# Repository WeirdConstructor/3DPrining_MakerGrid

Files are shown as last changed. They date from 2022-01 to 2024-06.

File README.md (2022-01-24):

# MakerGrid - A 3D Printed grid system for makers

This system allows you to temporarily setup electronics or other
devices on an extensible modular base platform:

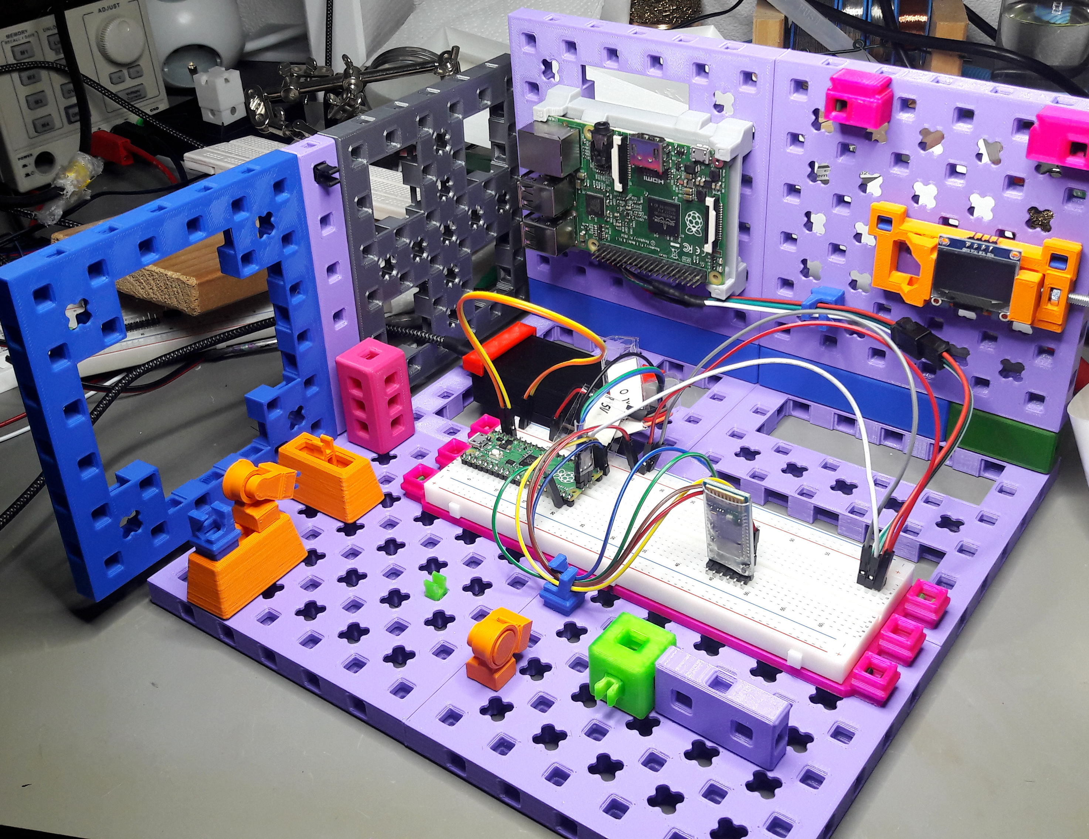
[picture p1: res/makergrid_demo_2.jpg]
MakerGrid Demonstration Prototype


The base is this 12x12cm big and 1cm high base platform:

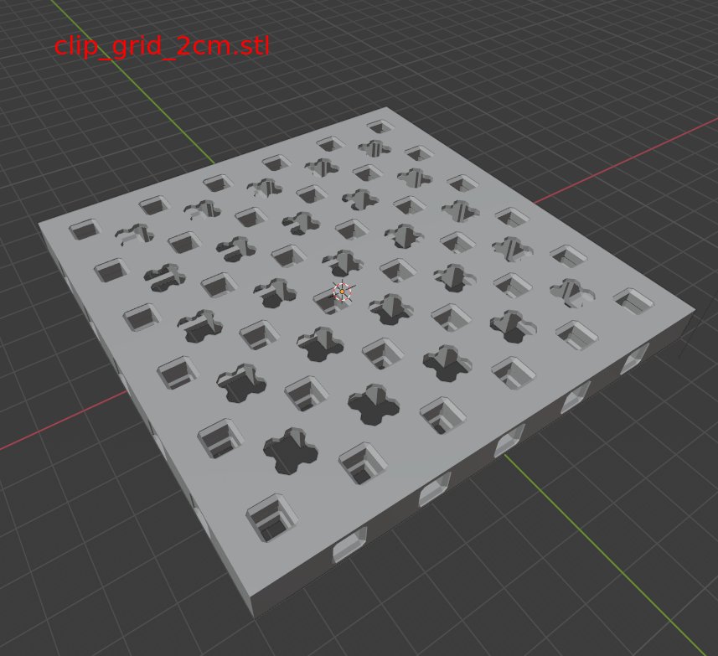
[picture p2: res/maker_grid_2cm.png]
MakerGrid 12x12cm base platform with 2x2cm clip grid


The primary base platform is 12x12cm big, 1cm high and has a 2x2cm grid for
clipping in all sorts of stuff, such as:

- Bread boards
- Electronics modules such as:
  - Arduino Uno / Nano
  - Raspberry Pi 4
  - Raspberry Pi Pico

The system is extensible as with the generic clip design you can make
your own models to clip into the board. A clip looks like this:

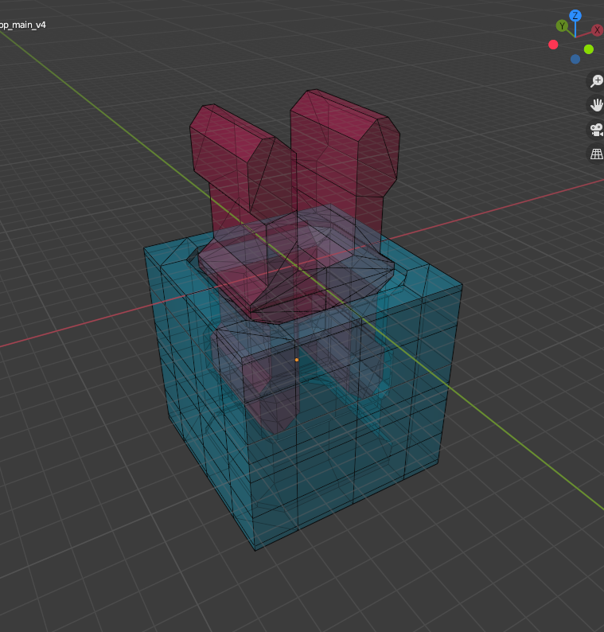
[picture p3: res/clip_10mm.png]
MakerGrid Clip


The clips hold well in the holes, you will need either strong fingers or
pliers to pull them out again. The clip arms will be printed with 3 0.4mm thick
walls, which provide enough flexibility while also holding tight.
The clips also provide a rotational stability.

The advantage of this system that connects holes is also,
that if you damage a clip, you can reprint them quickly.

There is a whole palette for holdes/clip holders to choose from in the `clip.blend`
file:

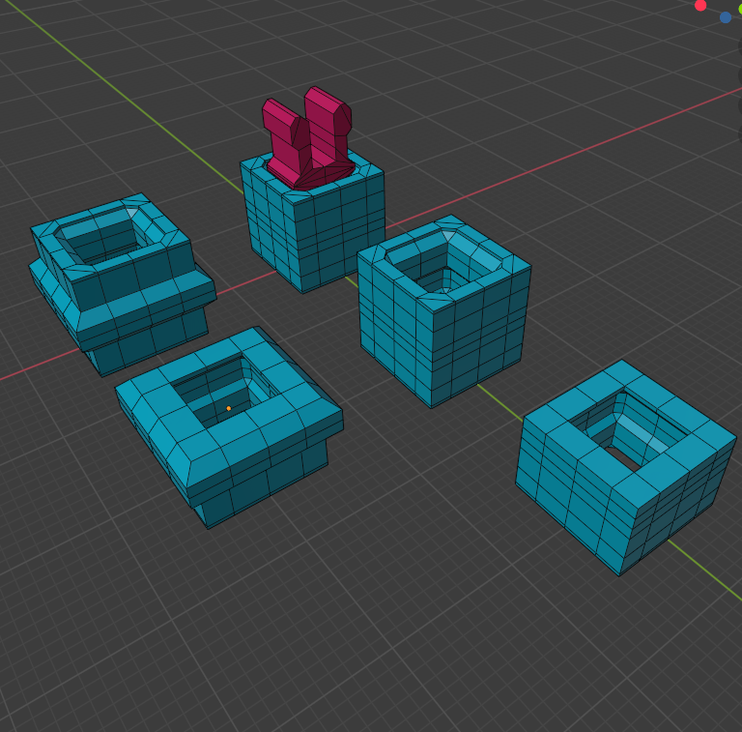
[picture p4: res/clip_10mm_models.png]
MakerGrid Clip Palette


## Prior Art

I was inspired by:

- 3D Printing Professor's PrintABlok
  - While I like this approach and it's design is superior to mine, I wanted
    something a bit more compact and less bulky.
  - https://www.youtube.com/watch?v=BU7ZYPHWDo4
  - https://www.3dpprofessor.com/product/printablok-base-set-free/
  - https://www.thingiverse.com/thing:4965875
- Pin Connectors V2
  - I like the simplicity of this design, but these round connectors
    would make the MakerGrid too wobbly if not connected by at least two
    pins. My grid clips are rectangular and already provide some stability
    if you just plug in a single one.
  - https://www.thingiverse.com/thing:10541

## Maker Grid Types:

- Regular Full:
MakerGrid 12x12cm base platform with 2x2cm clip grid
- Type B:
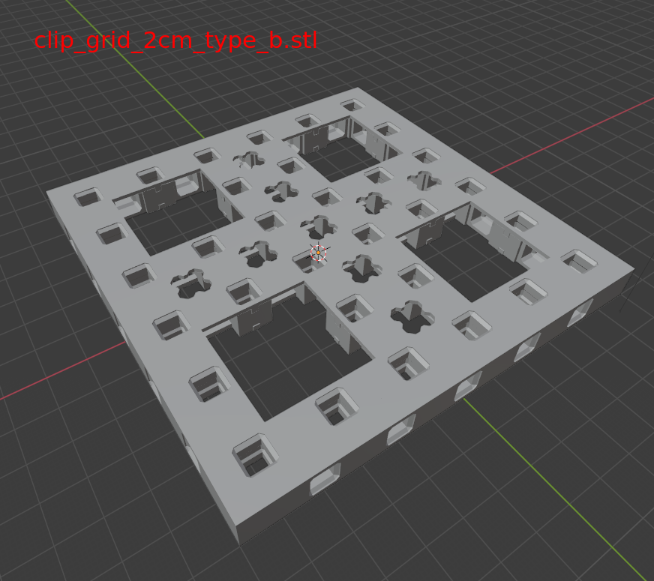
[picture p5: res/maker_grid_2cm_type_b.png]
MakerGrid 12x12cm base platform type B

- Type C:
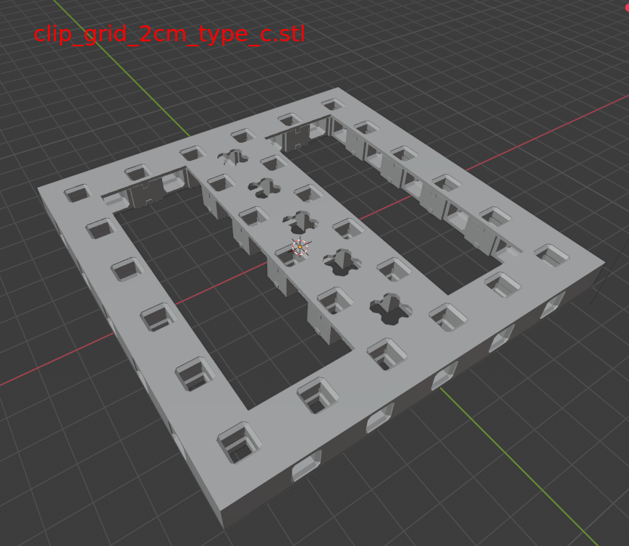
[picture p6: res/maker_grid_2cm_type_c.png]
MakerGrid 12x12cm base platform type C

- Type D:
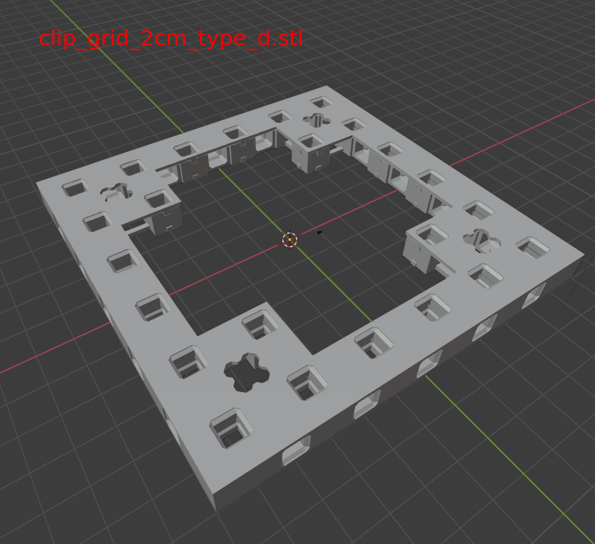
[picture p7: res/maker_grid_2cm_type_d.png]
MakerGrid 12x12cm base platform type D


## Utilities

- Build Cubes in sizes 1x1, 3x1, 7x1, 11x1, 15x1 offer a way to extend
  the maker grid into 3 dimensions.
    - Also with a slim variant that has the "\_s" as postfix.
    - And a base extension variant, that can be plugged to the side
      of the MakerGrid bases with an "\_x" postfix.

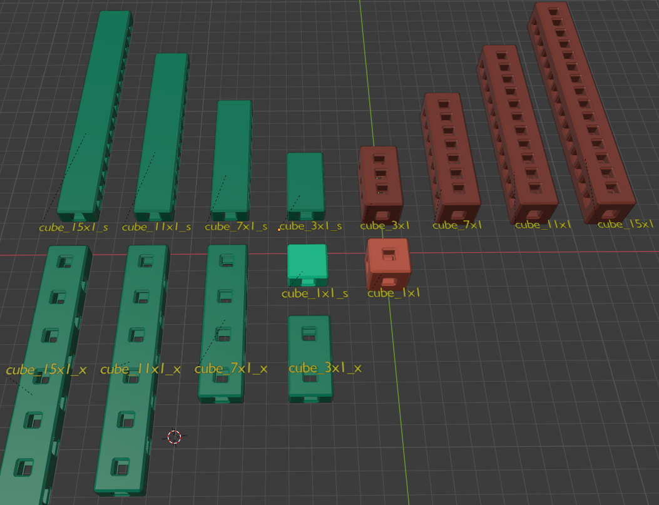
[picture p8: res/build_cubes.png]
MakerGrid Build Cubes


- Raspberry Pi 2/3/4 B Holder

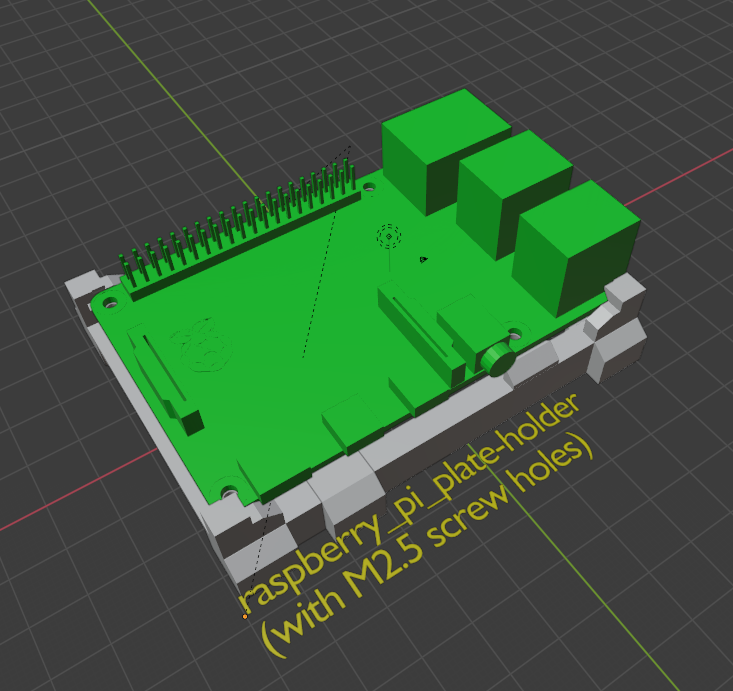
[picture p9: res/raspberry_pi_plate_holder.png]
Raspberry Pi Holder


- Raspberry Pico Holder

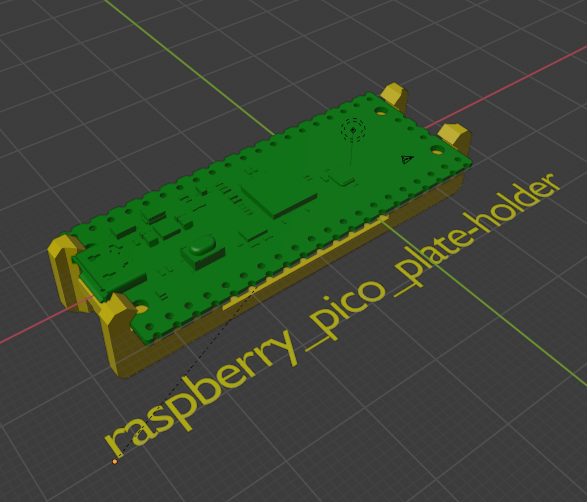
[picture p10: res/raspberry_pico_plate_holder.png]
Raspberry Pi Pico Holder


- **Make sure to checkout the subdirectory** `blender` **for more!**

## Recommended Printer Settings

Basically you can print it in any way you like, but I recommend
following settings for printing:

- 0.4mm nozzle
- 0.3mm layer height
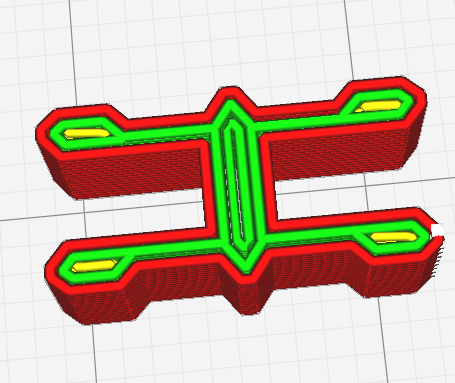
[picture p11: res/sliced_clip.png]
Sliced Maker Grid Clip
- For the clips themself I recommend a wall thickness of 1.6mm: 
For the other parts even 0.8mm works fine.

The rest you can vary to your likings. I printed it in PLA. Not tried
it in PETG or ABS/ASA yet, but should be even better for the clips (due to
better flexibility).

## License

3D MakerGrid by Weird Constructor is licensed under the
Creative Commons - Attribution - Share Alike license.

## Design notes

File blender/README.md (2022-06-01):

# MakerGrid Blender and STL Files

Here are the Blender files that are used to generate the
STL files that you can find here. Here is an STL index:

## Basic MakerGrid Parts

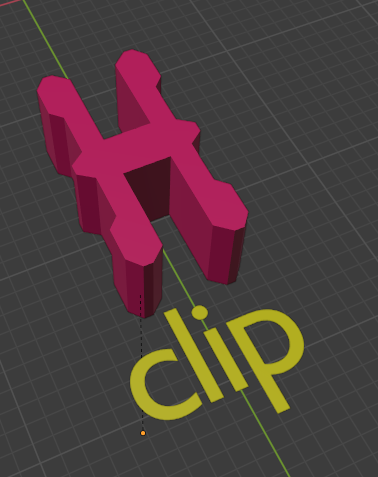
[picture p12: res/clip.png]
MakerGrid Clip


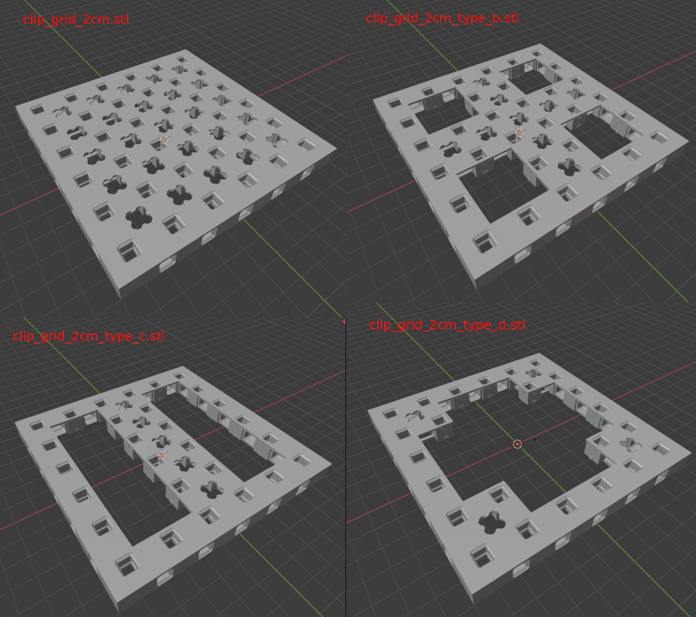
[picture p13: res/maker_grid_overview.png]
MakerGrid Overview


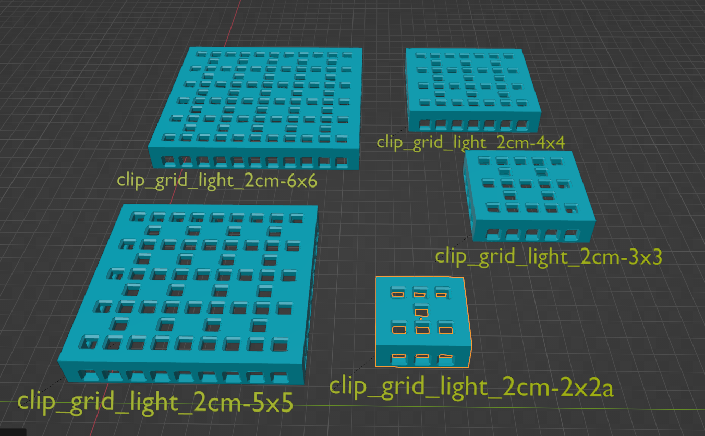
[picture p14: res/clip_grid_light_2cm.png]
MakerGrid Grid Light


## Utilities

You can find more stuff in the subdirectories:

- `cases` assorted cases and holders for electronics.
- `utils` all kinds of useful stuff to plug onto your MakerGrid.
- `devices` specific devices made for the MakerGrid.

## Miscellaneous 

- `clip-mini_clip_holder.stl` is a base holder you can drop into new designs
for small cases. It's like a small version of the bigger clip, but directed
directly towards case design.
    - `clip-mini_clip.stl` the corresponding clip.

## PrintABlok Compatibility Models

In the `mak_a_blok.blend` file you find the following adapter files
that make it possible to combine parts of the MakerGrid and PrintABlok system.

**Attention:** These PrintABlok parts are under the CC-BY-NC 4.0 license and not
under CC-BY-SA like the rest of the MakerGrid system!

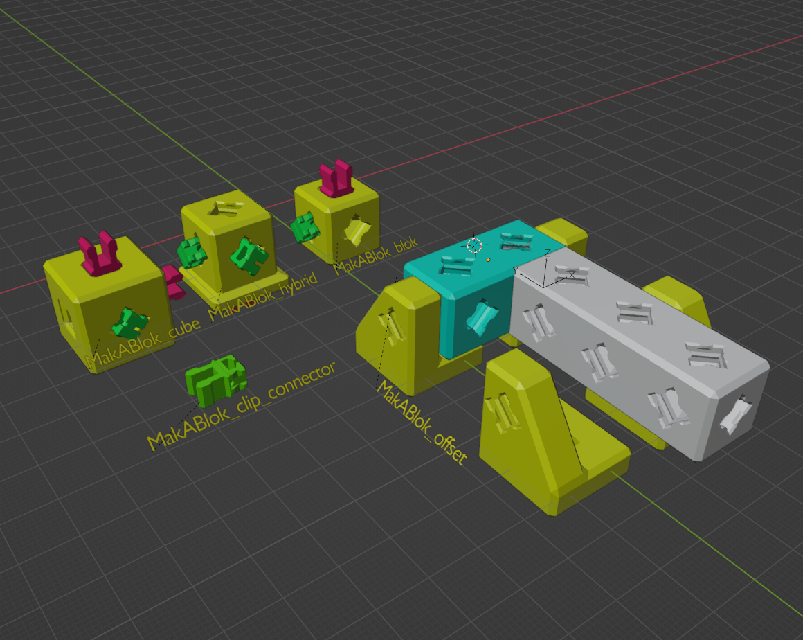
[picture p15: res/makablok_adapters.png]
MakABlok


See also the STL files:

- [PrintABlok MakerGrid Clip Connector](mak_a_blok-MakABlok_clip_connector.stl)
- [PrintABlok MakerGrid hybrid cube with offset for combining 16mm and 20mm](mak_a_blok-MakABlok_offset.stl)
- [PrintABlok block with MakerGrid hole](mak_a_blok-MakABlok_blok.stl)
- [PrintABlok block with MakerGrid wide base hole](mak_a_blok-MakABlok_hybrid.stl)
- [MakerGrid cube with PrintABlok holes](mak_a_blok-MakABlok_cube.stl)

## License

3D MakerGrid by Weird Constructor is licensed under the
Creative Commons - Attribution - Share Alike license.

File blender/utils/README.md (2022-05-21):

# Utilities for MakerGrid Blender and STL Files

A collection of assorted utilities for the MakerGrid:

MakerGrid Build Cubes

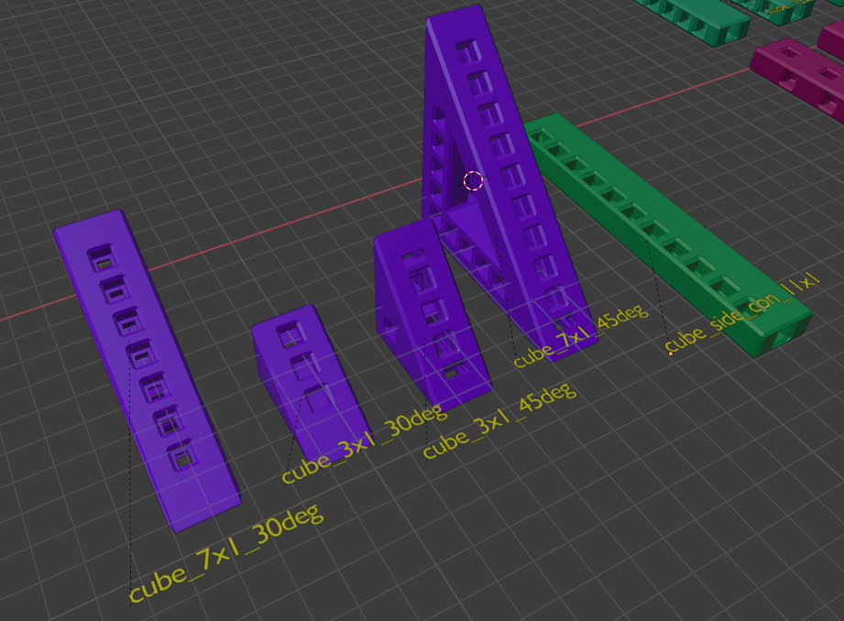
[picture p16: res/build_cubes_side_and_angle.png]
MakerGrid Build Cubes Angles and Base Wall Joints


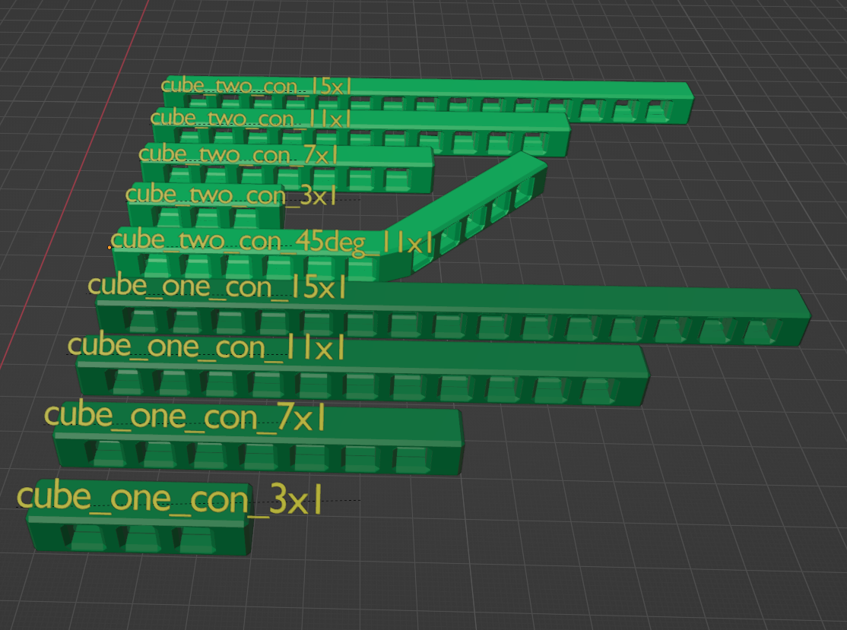
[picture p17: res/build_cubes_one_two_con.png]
MakerGrid Build Cubes One-/Two-Side Connection


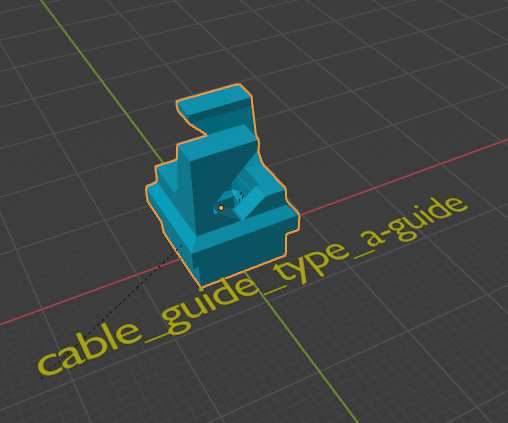
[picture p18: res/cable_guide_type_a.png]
Cable Guide Type A


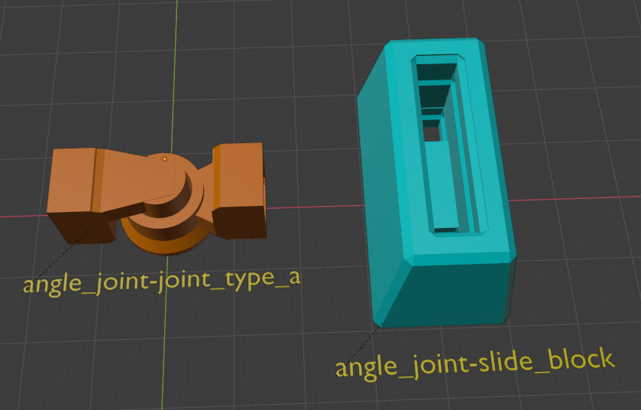
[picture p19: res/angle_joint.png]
Angle Joints


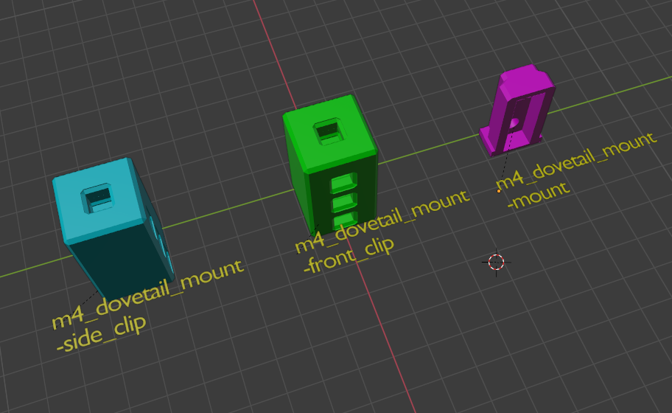
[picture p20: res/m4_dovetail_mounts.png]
M4 Dovetail Mounts


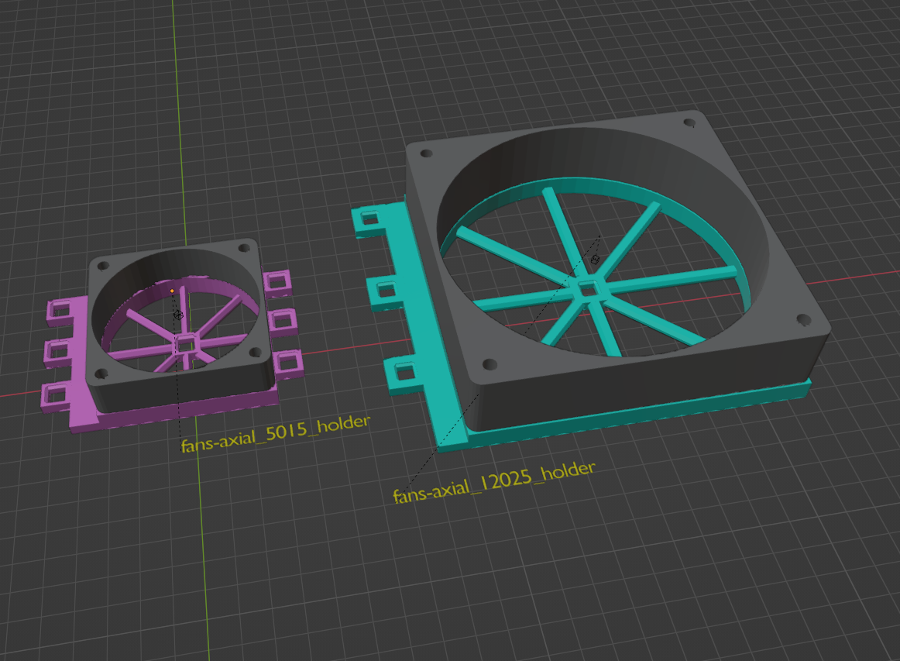
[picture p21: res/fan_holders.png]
Fan Holders


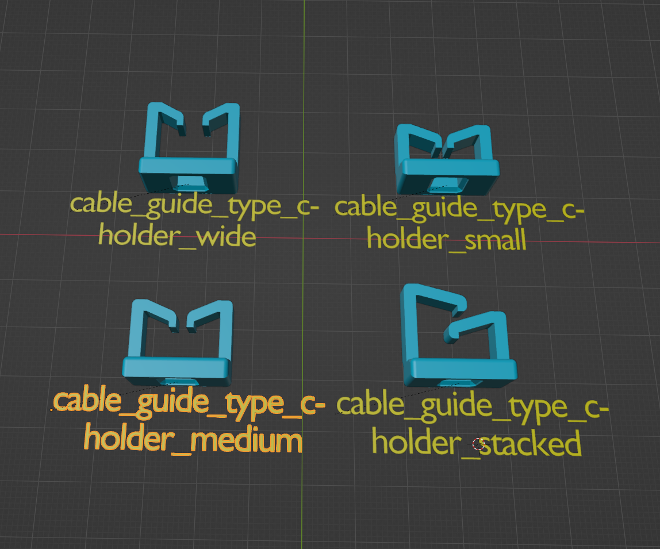
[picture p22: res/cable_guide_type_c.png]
Cable Guide Type C


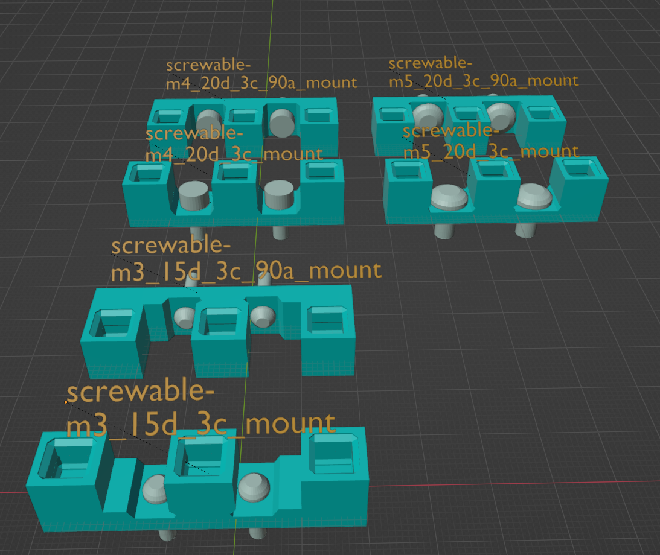
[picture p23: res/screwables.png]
Screwable Clip Holders


# Aluminum Extrusion Utils

20x20 Aluminum Extrusion T-Slot clips (attention, these are under GPLv3):

- [t_slot_profile_util-t_slot_20x20_nut_6_mkg_clip_loose_fit.stl](t_slot_profile_util-t_slot_20x20_nut_6_mkg_clip_loose_fit.stl)
- [t_slot_profile_util-t_slot_20x20_nut_6_mkg_clip_tight_fit.stl](t_slot_profile_util-t_slot_20x20_nut_6_mkg_clip_tight_fit.stl)

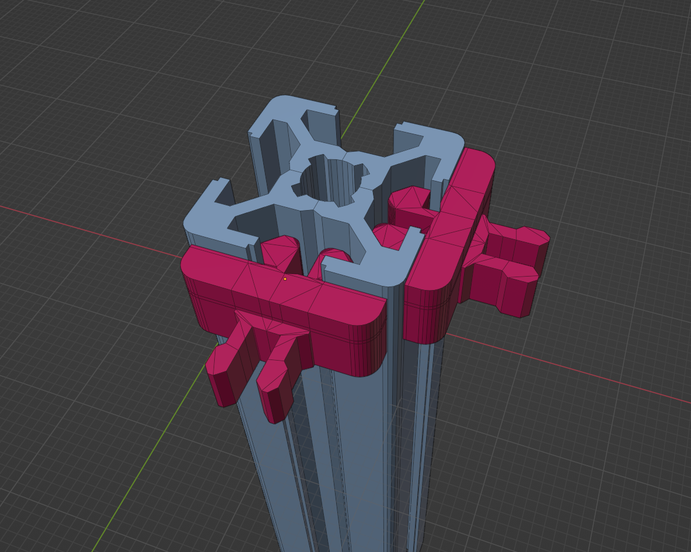
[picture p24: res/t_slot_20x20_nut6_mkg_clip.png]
T-Slot MakerGrid Clips


The T-Slot side has been derived from: https://www.printables.com/model/54744-2020-cable-clips-t-slot-v-slot

    2020 cable clips (T-Slot & V-Slot) by Shaun Doe
    This work is licensed under a GNU General Public License v3.0
    which is Adapted from the (V-slot only) cable-clips
    of the Bear Upgrade as created by Grégoire Saunier. Created
    using the 2.1.0 source files.

## License

3D MakerGrid by Weird Constructor is licensed under the
Creative Commons - Attribution - Share Alike license.

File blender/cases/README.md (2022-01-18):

# MakerGrid Blender and STL Files for Cases

Here you find assorted case designs you can plug onto the MakerGrid.

Raspberry Pi 2/3/4 Holder

Raspberry Pi Pico Holder

## License

3D MakerGrid by Weird Constructor is licensed under the
Creative Commons - Attribution - Share Alike license.

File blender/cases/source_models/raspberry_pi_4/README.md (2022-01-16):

# Raspberry Pi 4 3D Model from Thingiverse by OculusQuest

Raspberry Pi 4 3D Model for Case development by
OculusQuestis licensed under theCreative Commons - Attribution - Non-Commercial - Share Alike license.

By downloading this thing, you agree to abide by the license: Creative Commons - Attribution - Non-Commercial - No Derivatives

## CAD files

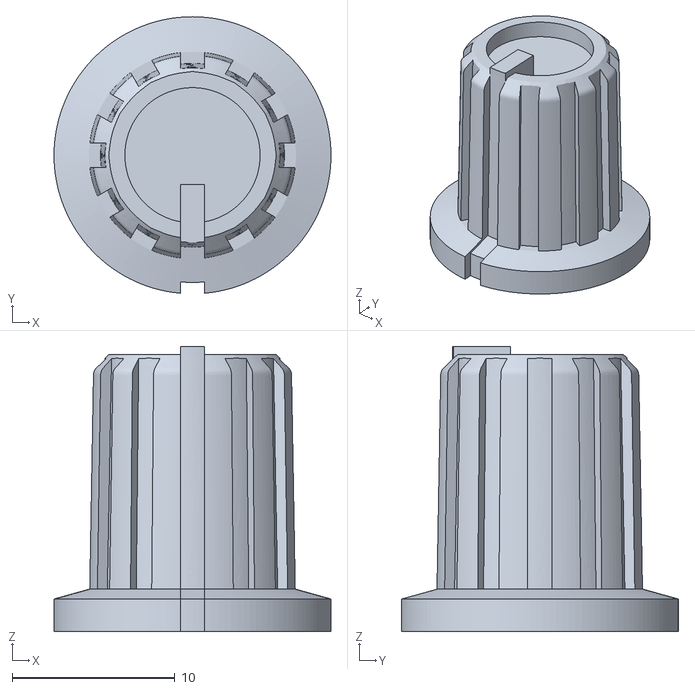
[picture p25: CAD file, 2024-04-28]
blender/devices/main_knob.stl
17.0 x 17.0 x 17.5

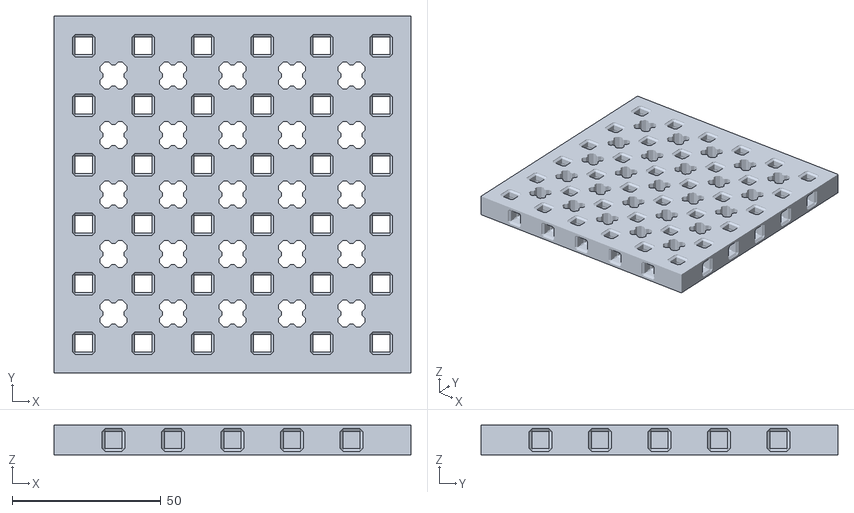
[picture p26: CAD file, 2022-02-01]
blender/clip_grid_2cm-grid_2cm_full.stl
120.0 x 120.0 x 10.0

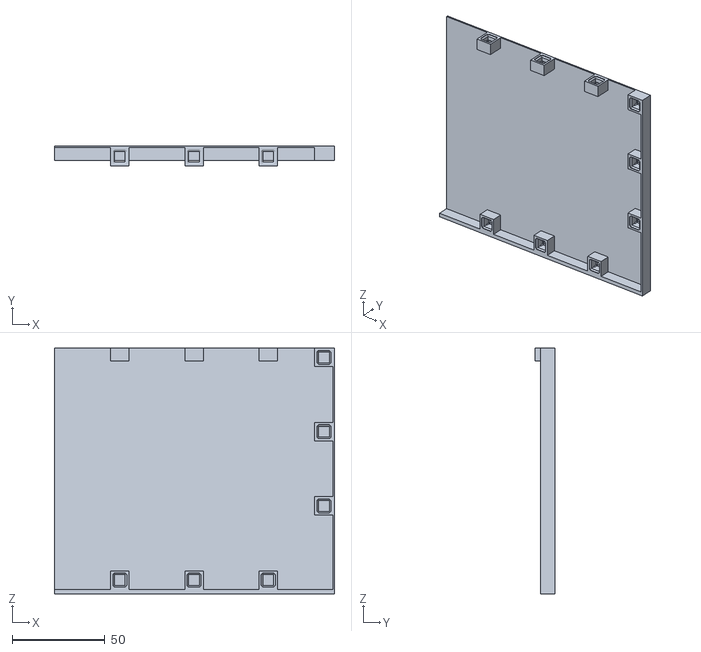
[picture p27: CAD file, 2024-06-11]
blender/cases/case_200x150x130-right_side.stl
150.9 x 10.7 x 132.4

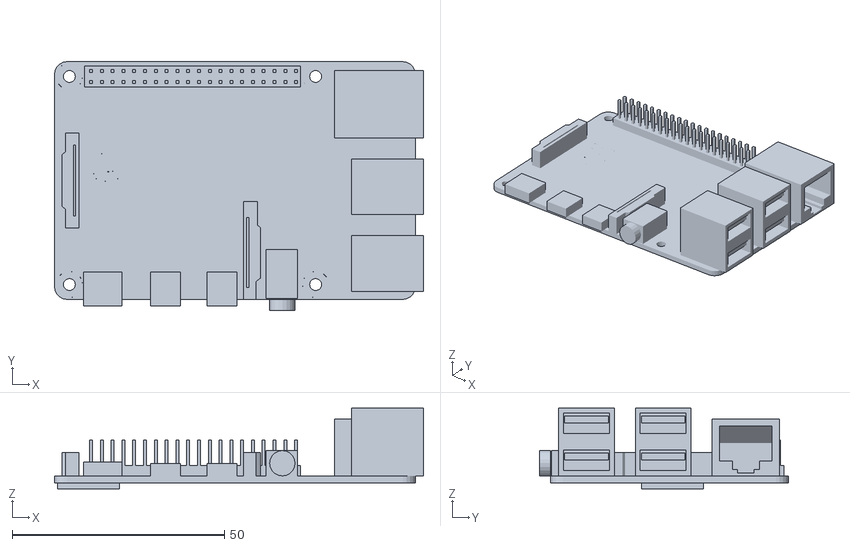
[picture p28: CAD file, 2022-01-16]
blender/cases/source_models/raspberry_pi_4/Raspberry_Pi_4_B_3D_Model.obj
86.9 x 58.6 x 19.0

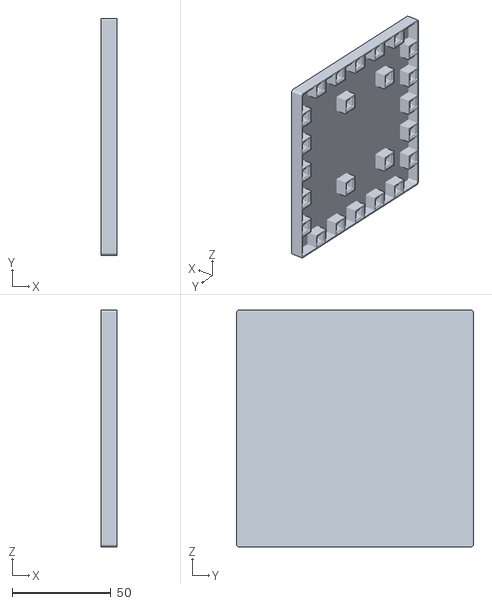
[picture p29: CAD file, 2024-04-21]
blender/clip_grid_2cm_case-cover_12x12.stl
7.89 x 120.0 x 120.0

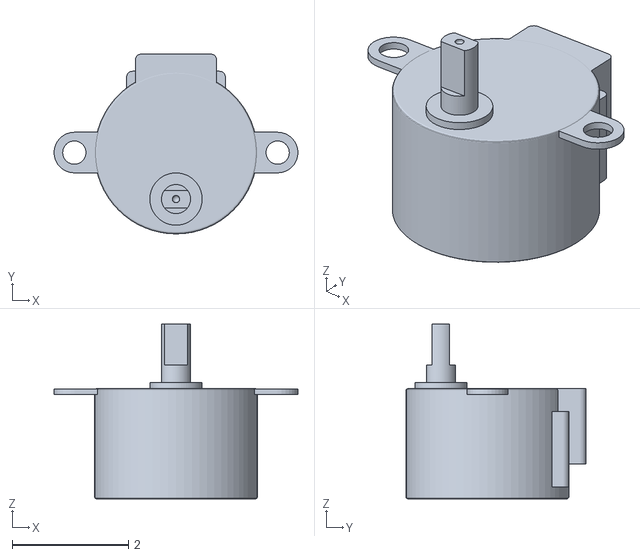
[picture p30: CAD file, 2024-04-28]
blender/devices/StepMotorModel.stl
4.20 x 3.10 x 3.01

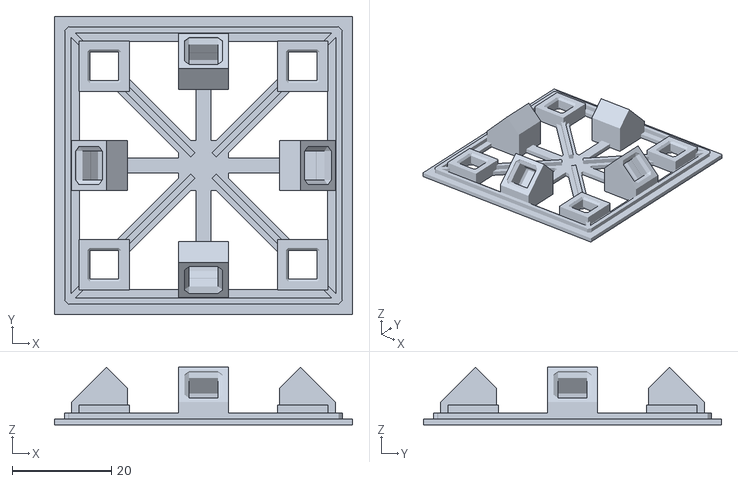
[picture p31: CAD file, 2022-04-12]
blender/frame/frame-box_60x60.stl
60.0 x 60.0 x 11.7

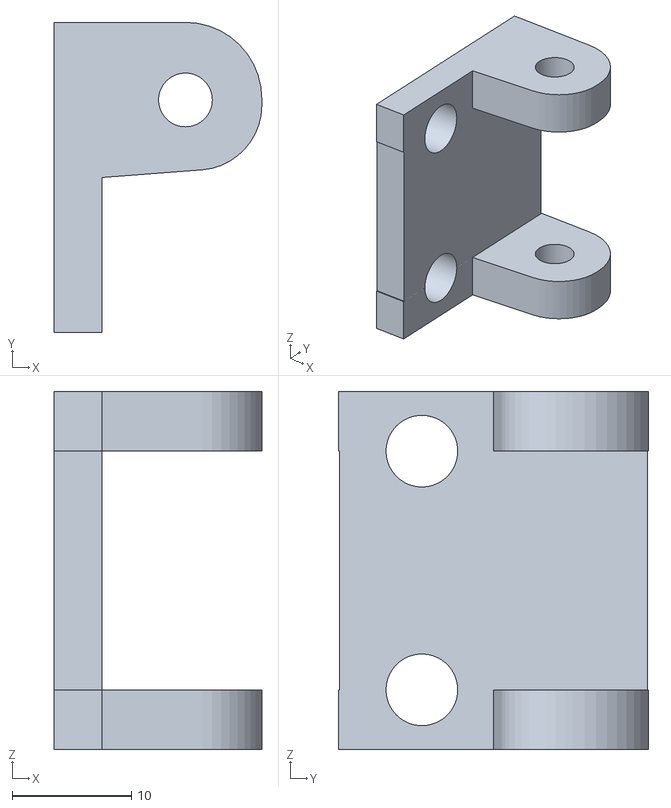
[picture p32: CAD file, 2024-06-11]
blender/utils/plant_guide-frame_hinge.stl
17.4 x 26.0 x 30.0

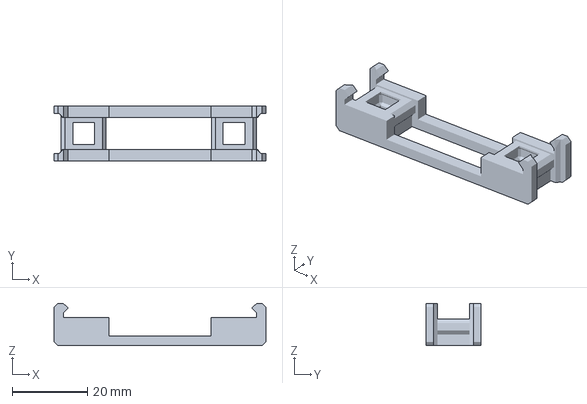
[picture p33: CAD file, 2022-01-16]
sliced/sliced_anycubic_i3_mega/raspberry_pico_plate-holder.3mf
56.4 x 14.6 x 11.2 mm

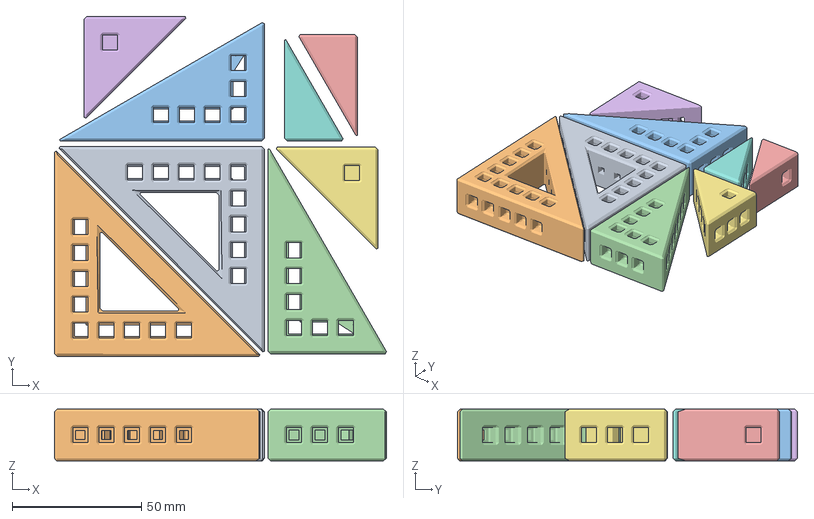
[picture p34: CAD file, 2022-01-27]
sliced/sliced_kp3s/2xbuild_cubes-cube_30_45deg.3mf
128.2 x 131.3 x 20.0 mm
build_cubes-cube_7x1_45deg.stl
build_cubes-cube_7x1_45deg.stl(1)
build_cubes-cube_7x1_30deg.stl
build_cubes-cube_7x1_30deg.stl(1)
build_cubes-cube_3x1_30deg.stl
build_cubes-cube_3x1_45deg.stl
build_cubes-cube_3x1_45deg.stl(1)
build_cubes-cube_3x1_30deg.stl(1)

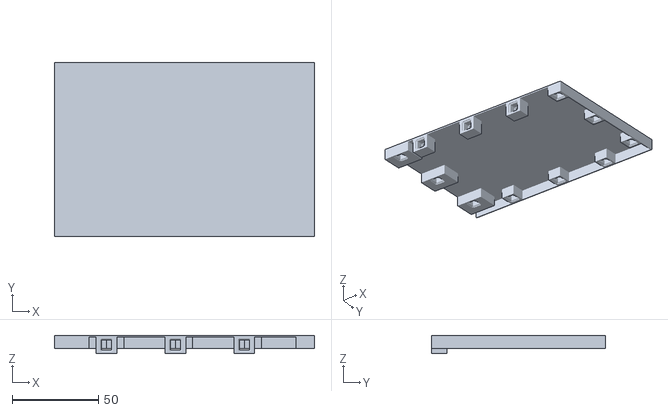
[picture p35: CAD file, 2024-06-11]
blender/cases/case_200x150x130-top_right.stl
150.9 x 100.9 x 10.7

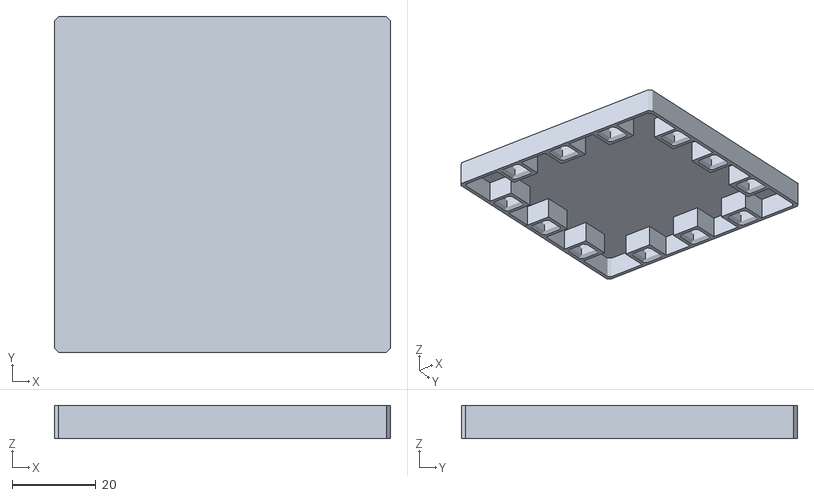
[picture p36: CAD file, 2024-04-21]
blender/clip_grid_2cm_case-cover_8x8.stl
80.0 x 80.0 x 7.89

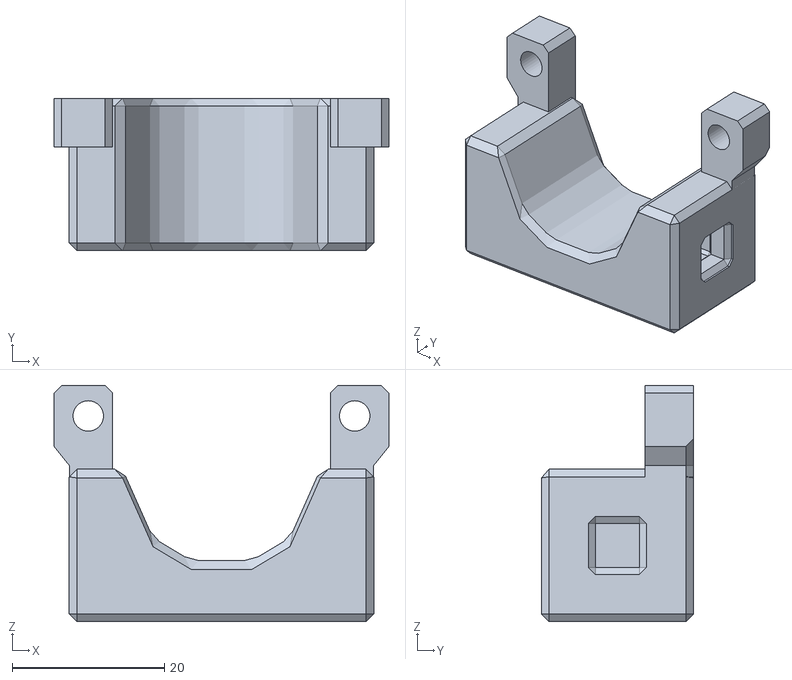
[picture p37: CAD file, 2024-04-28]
blender/devices/28byj-48_stepper_step_motor_holder-motor_mount.stl
44.0 x 20.0 x 31.0

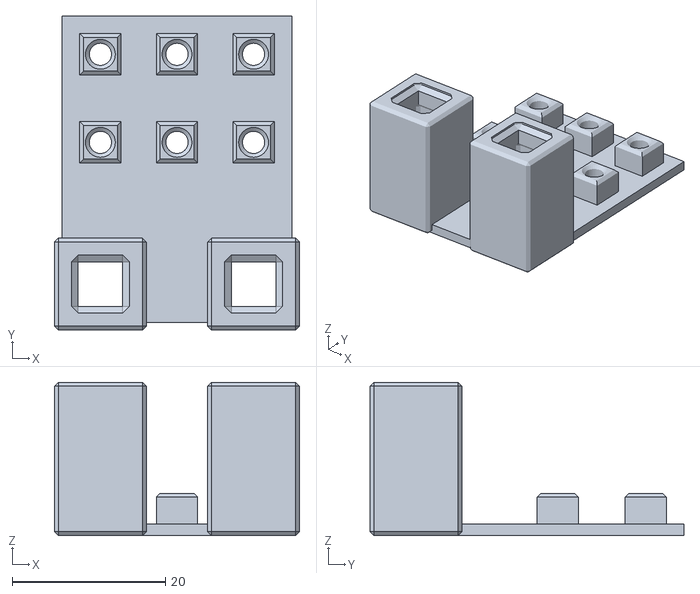
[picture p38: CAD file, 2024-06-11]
blender/utils/hole_grid-hole_grid_30x40.stl
32.0 x 41.0 x 20.0

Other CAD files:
blender/cases/source_models/raspberry_pi_4/Raspberry_Pi_4_B.STEP
sliced/sliced_anycubic_i3_mega/clip_grid_2cm_type_b.3mf
sliced/sliced_kp3s/build_cubes-cube_side_con_11x1.3mf
blender/cases/case_200x150x130-top_left.stl
blender/Arduino-UNO.stl
blender/cases/btt_octopus_plate-board_plate.stl
blender/cases/btt_octopus_plate.blend
blender/cases/case_200x150x130.blend
blender/cases/glue_plate-plate_55x83.stl
blender/cases/glue_plate.blend
blender/cases/grid_case-12x12_6mm_height.stl
blender/cases/grid_case-12x12_top.stl
blender/cases/grid_case-12x12_top_grid.stl
blender/cases/grid_case-side_4x12.stl
blender/cases/grid_case-side_8x12.stl
blender/cases/grid_case-wall_4x6.stl
blender/cases/grid_case-wall_8x6.stl
blender/cases/grid_case.blend
blender/cases/meanwell_lrs_350_24_holder-M4_screw_plate.stl
blender/cases/meanwell_lrs_350_24_holder.blend
blender/cases/powerplug_mount.blend
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

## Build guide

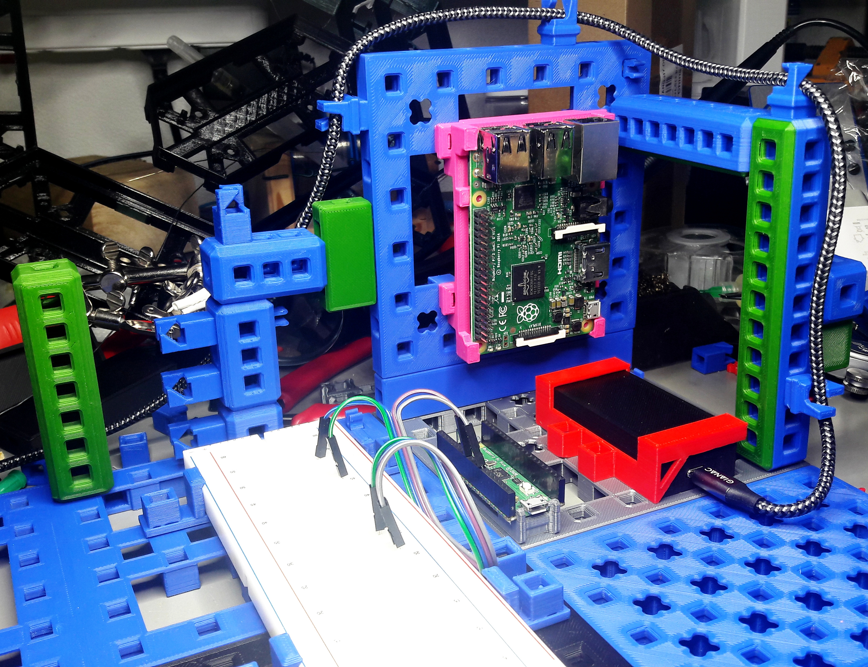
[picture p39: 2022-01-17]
res/makergrid_demo_1.jpg

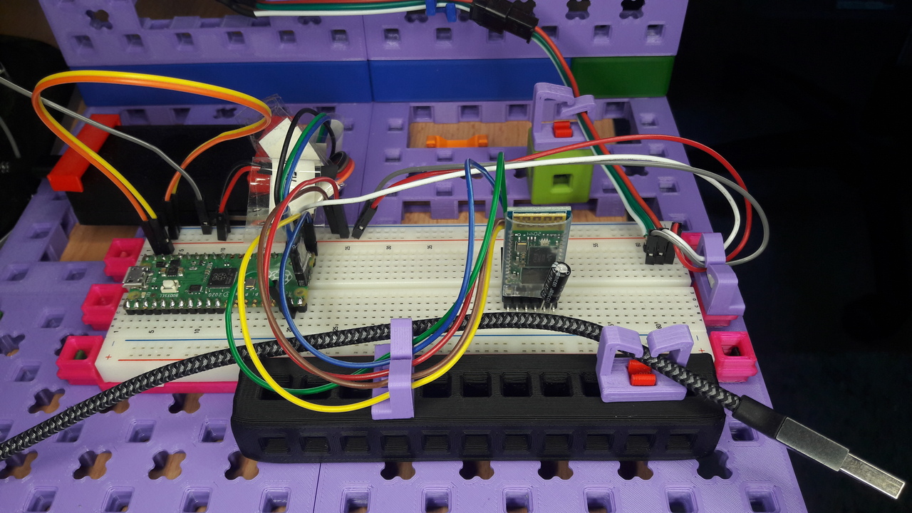
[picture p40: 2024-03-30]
res/cable_guide_type_c_demo2.jpg

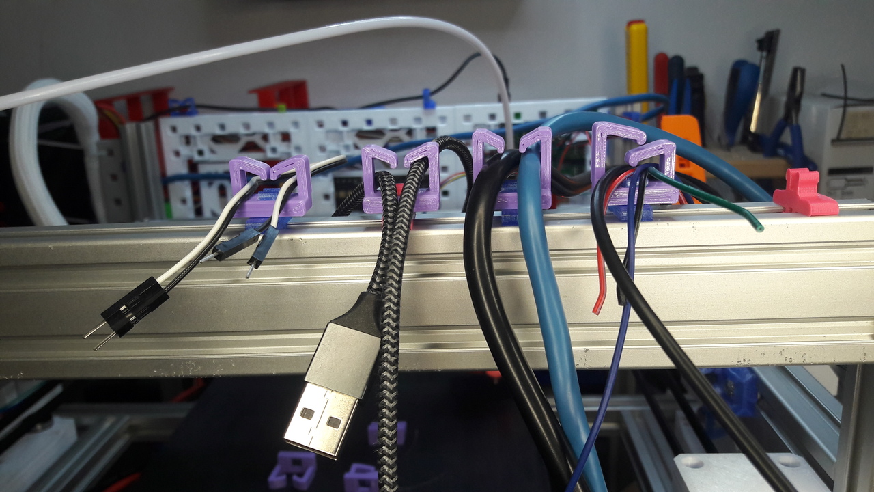
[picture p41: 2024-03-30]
res/cable_guide_type_c_demo.jpg

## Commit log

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2022-01-14 added screenshot for clip
    [clip.blend]
2022-01-14 added type B and C
    [clip.blend, clip_grid_2cm.3mf, clip_grid_2cm.blend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]
2022-01-14 made more alternative types
    [clip_grid_2cm.blend, clip_grid_2cm_r2.3mf, clip_grid_2cm_r2.stl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]
2022-01-14 designed makergrid pico case holder
    [clip.stl, clip_grid_2cm.blend, clip_grid_2cm_r2.3mf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]
2022-01-14 Designed a cable guide and improved the pico case holder
    [cable_guide_a_v1.3mf, cable_guide_a_v1.blend, cable_guide_a_v1.stl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]
2022-01-15 worked on the breadboard clamp and revised the clip hole design
    [breadboard_55mm_holder.blend, breadboard_55mm_holder_hor.stl, cable_guide_a_v1.blend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]
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2022-01-15 added more clip holder models
    [breadboard_55mm_holder.blend, clip.blend]
2022-01-15 cleaned up cable guide files
    [cable_guide_a_v1.blend, cable_guide_a_v1.stl, cable_guide_a_v2.stl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]
2022-01-15 reworked holes in grid file
    [clip.blend, clip_grid_2cm.blend, clip_grid_2cm_r2.3mf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]
2022-01-15 added bridges to the bottom for more strength
    [clip_grid_2cm.blend, clip_grid_2cm.stl]
2022-01-15 Completely reworked the grids with two way clip holder holes
    [build_cubes.blend, cable_guide_a_v2.3mf, clip.blend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]
2022-01-16 added more constructive parts
    [build_cubes.blend, cube_1x1.3mf, cube_1x1.stl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]
2022-01-16 fixed 2x1 cube
    [build_cubes.blend]
2022-01-16 Added build cube utilities in multiple sizes
    [build_cubes.blend, cube_1x1_s.stl, cube_3x1_s.stl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]
2022-01-16 improved the clip design and the cube export orientation.
    [build_cubes-cube_11x1.stl, build_cubes-cube_11x1_s.stl, build_cubes-cube_15x1.stl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]
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2022-01-16 Added Raspberry Pi PCB holder
    [Raspberry_Pi_4_B.SLDPRT, Raspberry_Pi_4_B.STEP, Raspberry_Pi_4_B_3D_Model.obj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]
2022-01-17 more work on the cubes and clip settings
    [build_cubes-cube_11x1.stl, build_cubes-cube_15x1.stl, build_cubes-cube_1x1.stl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]
2022-01-18 finished raspberry PI holder and added mini clips.
    [clip-clip.stl, clip-mini_clip.stl, clip-mini_clip_holder.stl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]
2022-01-18 made build cube screenshot update
    [build_cubes.blend, clip.blend]
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2022-01-18 added more documentation and README files
    [build_cubes-cube_15x1_x.stl, build_cubes-cubes_x.3mf]
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2022-01-18 added raspberry pico image
    [cable_guide_type_a.blend, raspberry_pico_plate.blend]
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2022-01-18 developed an angle joint
    [angle_joint-joint_type_a.stl, angle_joint-slide_block.stl, angle_joint.blend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]
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2022-01-19 working on a small generic vise holder
    [vise_holder-vise_4cm.stl, vise_holder.blend]
2022-01-20 added m4 dovetail mount and finished the vise mount
    [m4_dovetail_mount-dovetail_cube_front.stl, m4_dovetail_mount-dovetail_cube_side.stl, m4_dovetail_mount.blend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]
2022-01-22 Added a large vise (for breadboard) and a PTFE tube holder
    [m4_dovetail_mount.blend, ptfe_tube-holder.stl, ptfe_tube.blend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]
2022-01-24 added LED panel holds and the glue plate
    [glue_plate-plate_55x83.3mf, glue_plate-plate_55x83.stl, glue_plate.blend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]
2022-01-24 new demo, and adjusted the clip blender file layout
    [clip.blend]
2022-01-27 added 30° and 45° angles and a side connector for the bases
    [2xbuild_cubes-cube_30_45deg.3mf, build_cubes-cube_1x1_45deg.stl, build_cubes-cube_3x1_30deg.stl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]
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2022-02-01 added case elements for 12x12 maker grid bases
    [clip_grid_2cm-grid_2cm_full.stl, grid_case-12x12_6mm_height.stl, grid_case-side_8x12.stl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]
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2022-02-05 worked on the storage containers for the MakerGrid
    [grid_case-wall_4x6.stl, storage-4x4x3.stl, storage-4x4x5.stl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]
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2022-02-12 working on a little shelf system for the containers
    [clip-pole.stl, clip-pole_holder.stl, clip.blend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]
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2022-02-19 Fix broken geometry on the clip pole template
    [clip.blend]
2022-02-19 Completely redesign the shelf
    [cont_shelf.blend]
2022-02-21 Added larger shelf side and perfected it more
    [clip.blend, cont_shelf-side_30mm.stl, cont_shelf-side_50mm.stl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]
2022-02-22 finished 5cm container shelf and added remaining container STLs for now
    [cont_shelf.blend, container-12x14x5.stl, container-16x8x3.stl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]
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2022-03-17 Added holders for the BTT Octopus and an LRS-350-24 power supply
    [btt_octopus_plate-board_plate.stl, btt_octopus_plate.blend, build_cubes-cube_11x1_x.stl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]
2022-03-18 Added both ended clip holder and cable guide type b
    [cable_guide_type_b-plate.stl, cable_guide_type_b.blend, clip.blend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]
2022-03-18 Reinforced the cable guide tybe b
    [cable_guide_type_b-plate.stl, cable_guide_type_b.blend]
2022-03-28 added M5 dovetail mount, compatible to the M4 dovetail
    [m5_dovetail_mount-mount.stl, m5_dovetail_mount-mount_with_t_slot_align.stl, m5_dovetail_mount.blend]
2022-04-01 added minimal clip hold, a frame part prototype and a T-Slot dove tail hold for aluminum extrusions
    [clip.blend, frame-box_60x60.stl, frame.blend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]
2022-04-12 added more STL exports of the basic parts
    [clip-clip_holder_applied_trimmed_closed.stl, clip-clip_holder_minimal.stl, clip-clip_holder_negative_applied_trimmed.stl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]
2022-04-18 Developed t-slot profile clips and a new cable guide
    [cable_guide_type_c-holder.stl, cable_guide_type_c.blend, m5_dovetail_mount.blend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]
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2022-04-23 added angled build cube connector and axial 5015 fan holder
    [build_cubes-cube_two_con_45deg_11x1.stl, build_cubes.blend, fans-axial_5015_holder.stl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]
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2024-03-30 added more utils for rp2040, raspberry pi and arduino uno
    [Arduino-UNO.stl, case_200x150x130.blend, clip.blend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]
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
